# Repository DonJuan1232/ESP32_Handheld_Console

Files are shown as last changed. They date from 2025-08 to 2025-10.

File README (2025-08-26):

This project is for a self designed handheld console.
The idea is that I create a base framework so that other developers can easily create games for this "platform"

Because I wanted to learn how to design a PCB I decided to design a PCB (Also because I really didnt want to solder a lot of buttons to a prototype board :) )
Later in the projects life cycle I will add all the PCB and 3d model design files.

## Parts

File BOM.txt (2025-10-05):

Bill Of Materials for 1 "game console"

1x shell
1x lid
6x buttons
1x 2.4 inch tft ILI9341 lcd display 
1x 30 pin ESP32
5x Tactile Pushbutton Switch Momentary 4pin 6*6*6mm
1x small toggle switch | built in measurements: 8.5 x 13.5mm
1x Li-Po Battery 3.7V 1200mAh
1x Seeed Studio Lipo Rider Plus
4x 8mm long screws with a 1.8mm diameter

Hot glue to keep battery components in place

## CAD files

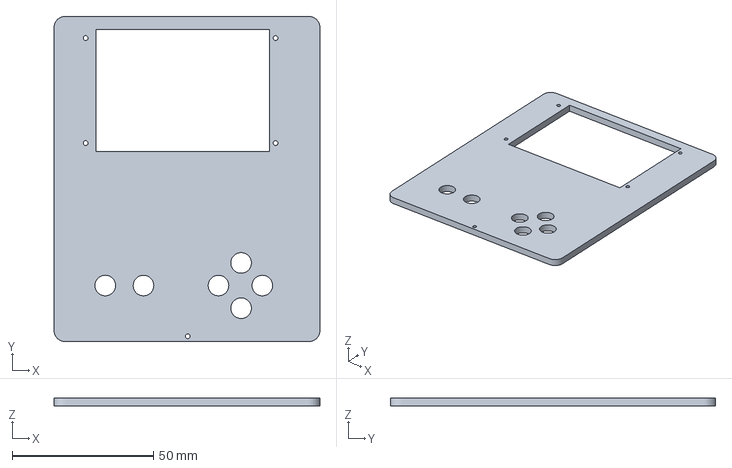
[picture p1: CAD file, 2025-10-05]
3d models/3d print files/Lid.3mf
94.0 x 115.0 x 3.00 mm

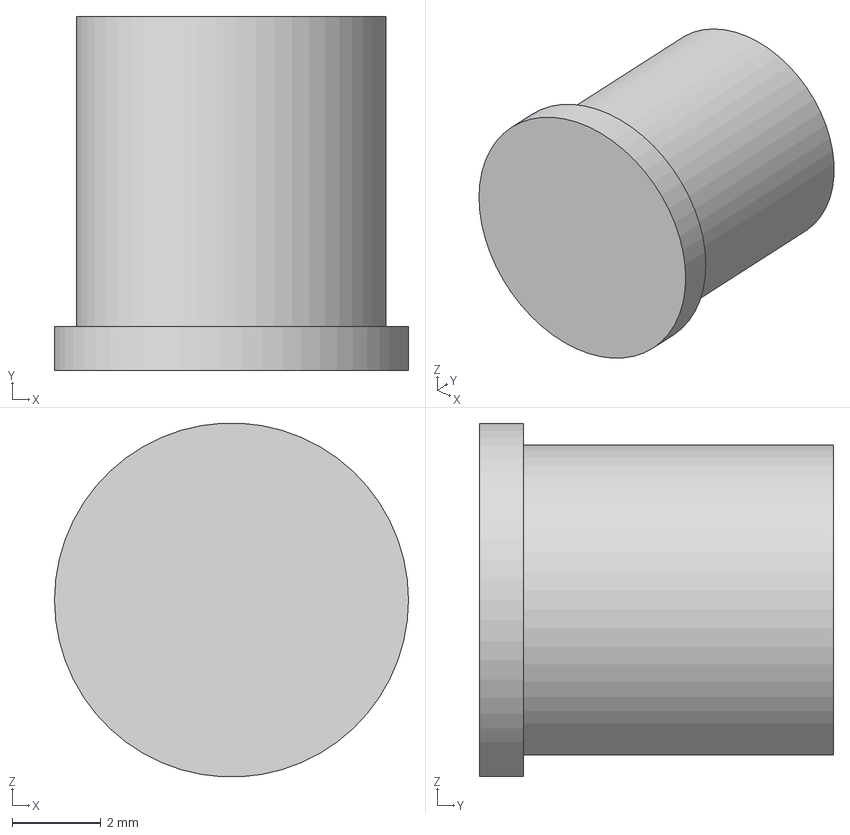
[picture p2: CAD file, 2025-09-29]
3d models/Button+cap.stp
8.00 x 8.00 x 7.99 mm

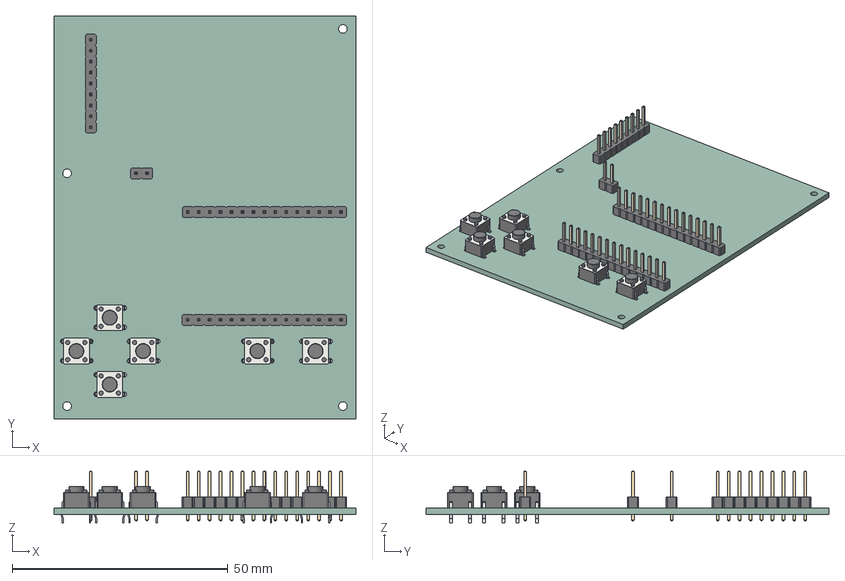
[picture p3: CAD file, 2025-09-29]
PocketGamePCB/PocketGamePCB.step
70.0 x 93.5 x 12.0 mm
PinHeader_1x15_P2.54mm_Vertical x 2
SW_PUSH_6mm_H5mm x 6
PinHeader_1x09_P2.54mm_Vertical
PinHeader_1x02_P2.54mm_Vertical
PocketGamePCB_PCB

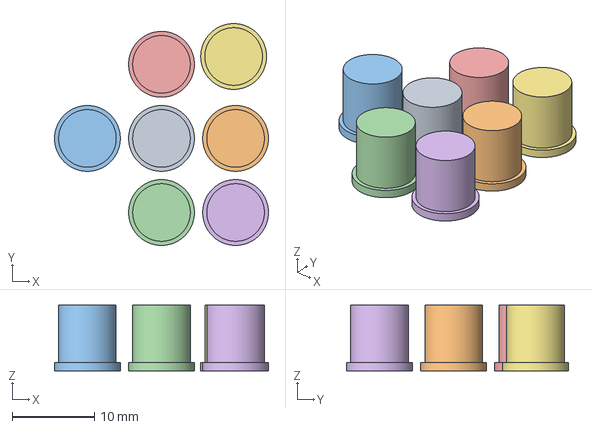
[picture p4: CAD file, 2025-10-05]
3d models/3d print files/buttons.3mf
26.0 x 26.9 x 8.00 mm

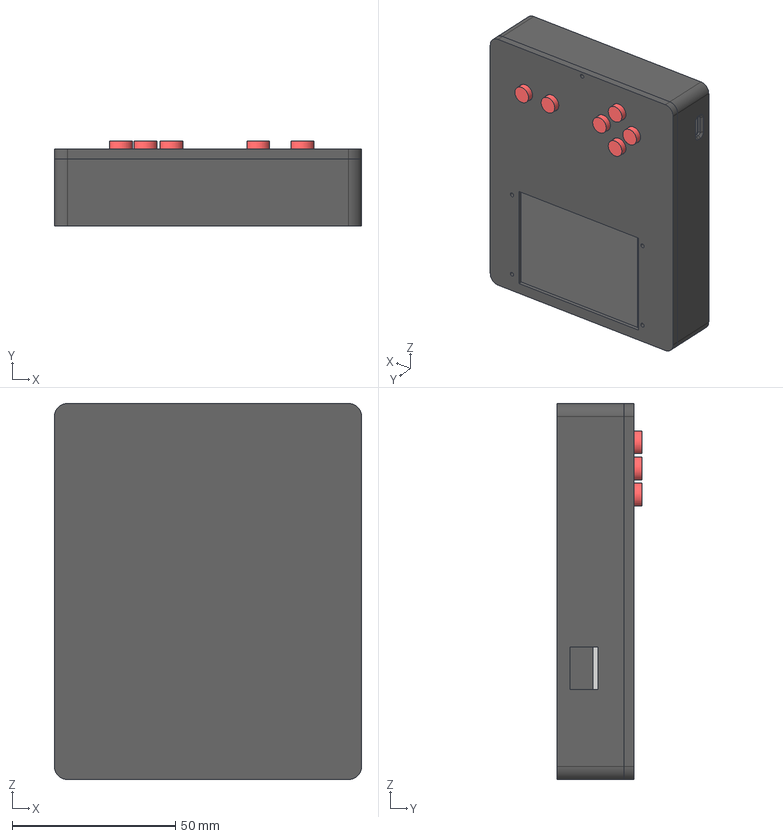
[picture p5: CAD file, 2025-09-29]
3d models/Pocket+Snake.stp
94.0 x 26.0 x 115.0 mm
2.4 inch tft lcd display
LID
Button cap x 6

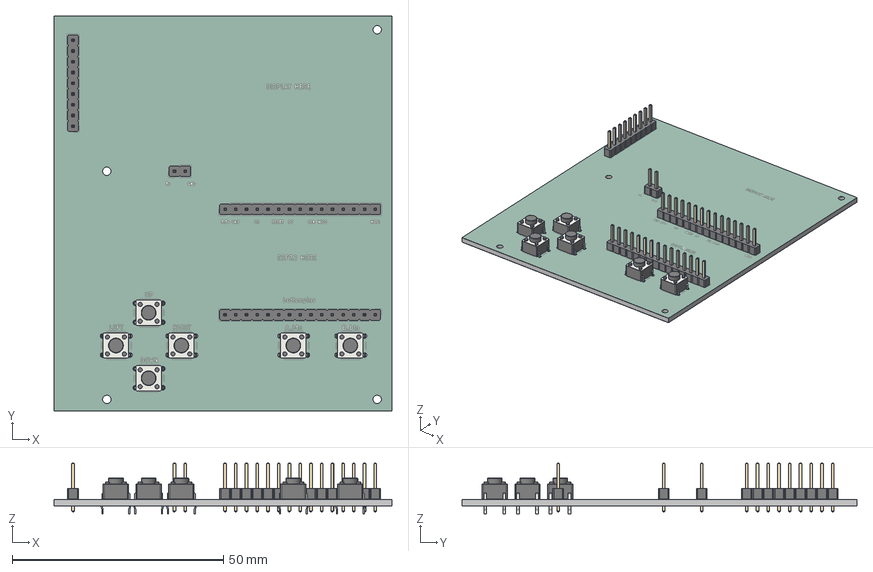
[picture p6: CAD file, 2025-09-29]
PocketGamePCB/PocketGamePCBnew.step
80.0 x 93.5 x 12.0 mm
PinHeader_1x15_P2.54mm_Vertical x 2
SW_PUSH_6mm_H5mm x 6
PinHeader_1x09_P2.54mm_Vertical
PinHeader_1x02_P2.54mm_Vertical
PocketGamePCB_silkscreen
PocketGamePCB_soldermask
PocketGamePCB_PCB

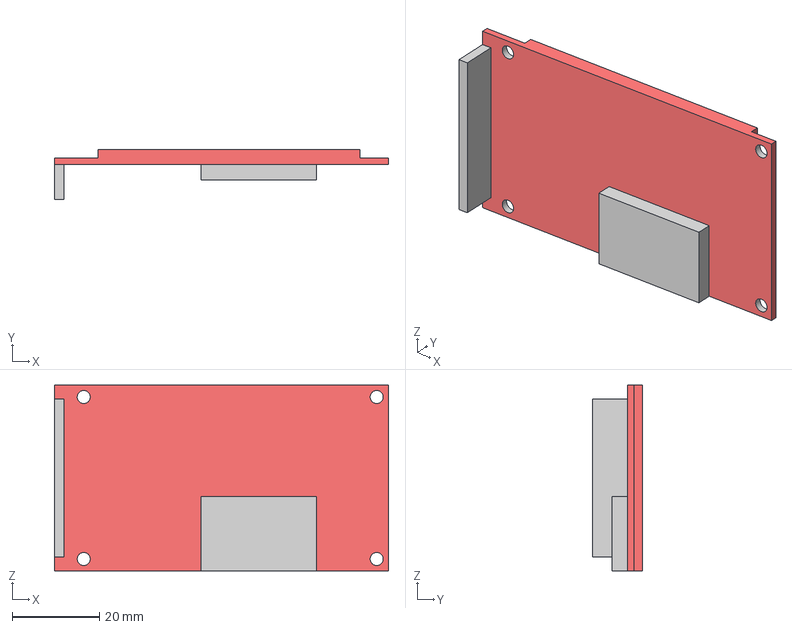
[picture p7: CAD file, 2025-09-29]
3d models/2.4 inch tft display.stp
76.5 x 11.5 x 42.5 mm

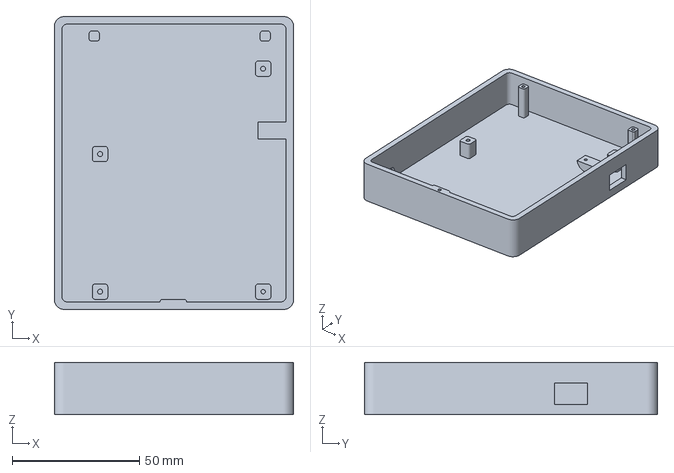
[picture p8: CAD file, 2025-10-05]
3d models/3d print files/Shell.3mf
94.0 x 115.0 x 20.5 mm

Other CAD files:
3d models/PocketGamePCBnew.stp

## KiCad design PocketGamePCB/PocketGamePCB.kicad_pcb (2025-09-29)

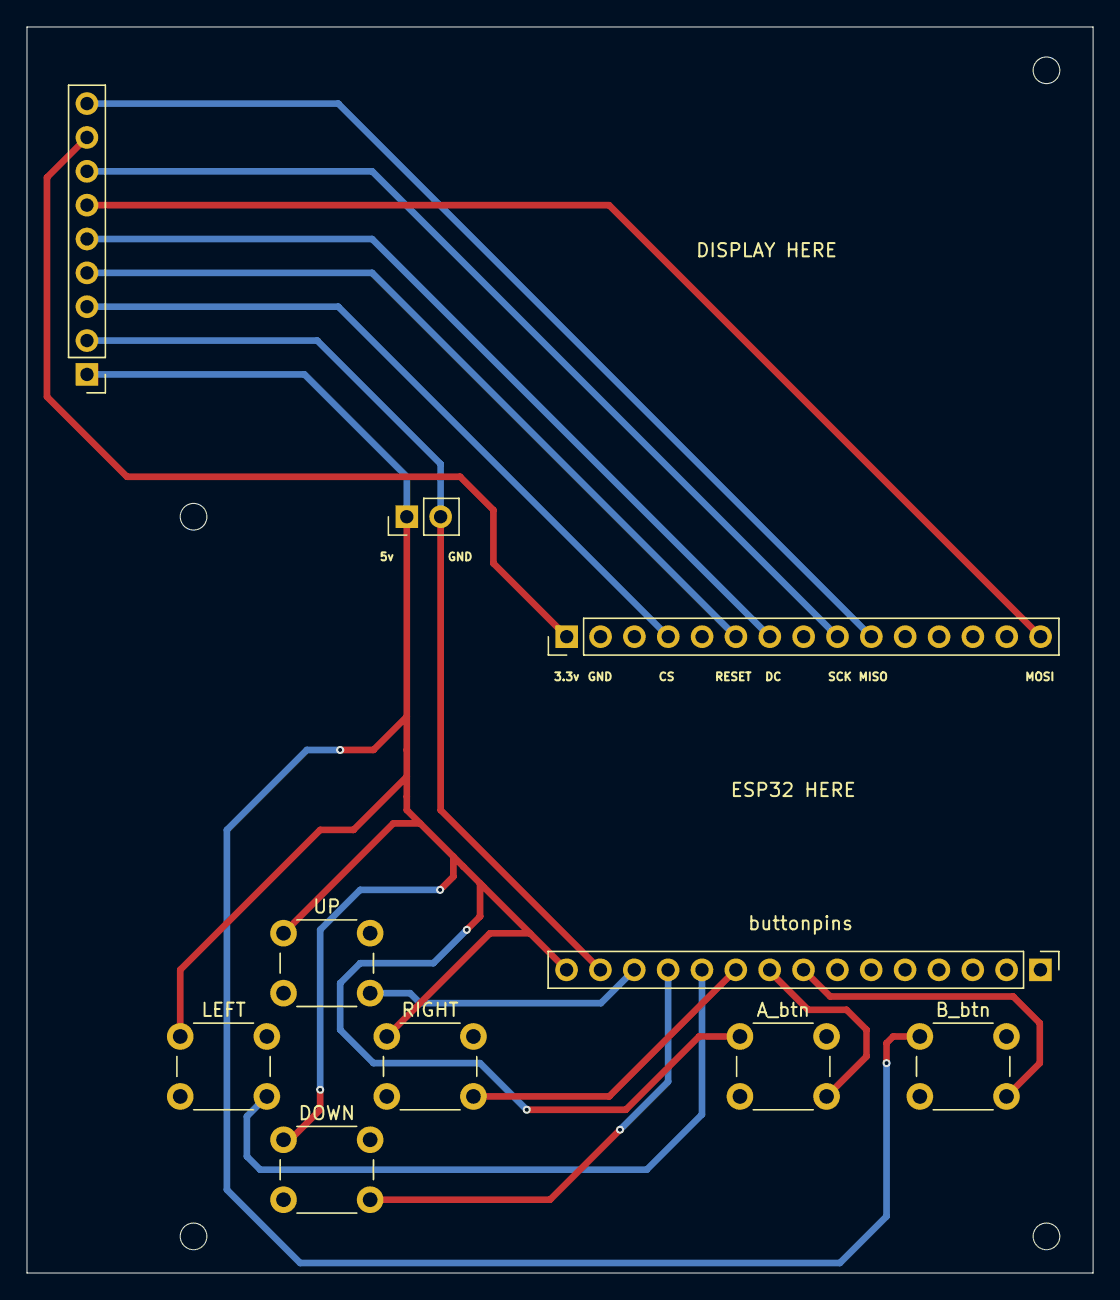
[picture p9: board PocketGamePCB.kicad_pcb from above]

Board: 2 copper layers, 80.0 x 93.5 mm, 10 parts (0 on the bottom side), 15 nets.

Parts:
5v: Conn_01x02_Pin; PinHeader_1x02_P2.54mm_Vertical
A_btn: SW_Push; SW_PUSH_6mm_H5mm
B_btn: SW_Push; SW_PUSH_6mm_H5mm
DOWN: SW_Push; SW_PUSH_6mm_H5mm
J1: Conn_01x15_Pin; PinHeader_1x15_P2.54mm_Vertical
J2: Conn_01x09_Pin; PinHeader_1x09_P2.54mm_Vertical
LEFT: SW_Push; SW_PUSH_6mm_H5mm
RIGHT: SW_Push; SW_PUSH_6mm_H5mm
UP: SW_Push; SW_PUSH_6mm_H5mm
buttonpins: Conn_01x15_Pin; PinHeader_1x15_P2.54mm_Vertical

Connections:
unnamed: J1.1, J2.8
unnamed: J1.4, J2.3
unnamed: J1.6, J2.4
unnamed: J1.7, J2.5
unnamed: J1.9, J2.7
unnamed: J1.10, J2.9
unnamed: J1.15, J2.6
unnamed: 5v.1, J2.1, buttonpins.14
unnamed: 5v.2, A_btn.1, B_btn.1, DOWN.1, J2.2, LEFT.1, RIGHT.1, UP.1, buttonpins.15
unnamed: B_btn.2, buttonpins.8
unnamed: A_btn.2, buttonpins.9
unnamed: RIGHT.2, buttonpins.10
unnamed: LEFT.2, buttonpins.11
unnamed: DOWN.2, buttonpins.12
unnamed: UP.2, buttonpins.13

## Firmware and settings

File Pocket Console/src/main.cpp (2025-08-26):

#include <Adafruit_GFX.h>
#include <Adafruit_ILI9341.h>
#include <freertos/FreeRTOS.h>
#include <freertos/task.h>
#include <stdlib.h>

#include "driver/gpio.h"
#include "esp_system.h"
#include "fruit.h"
#include "snake.h"
// Pin definitions
#define TFT_CS 2
#define TFT_DC 17
#define TFT_RST 16
#define LED_PIN 2
#define BUTTON_PIN_RIGHT 13
#define BUTTON_PIN_LEFT 12
#define BUTTON_PIN_DOWN 27
#define BUTTON_PIN_UP 14
#define BUTTON_PIN_A 25
#define BUTTON_PIN_B 26

Adafruit_ILI9341 display = Adafruit_ILI9341(TFT_CS, TFT_DC, TFT_RST);

const gpio_num_t buttonPinA = (gpio_num_t)BUTTON_PIN_A;
const gpio_num_t buttonPinB = (gpio_num_t)BUTTON_PIN_B;
const gpio_num_t buttonPinUp = (gpio_num_t)BUTTON_PIN_UP;
const gpio_num_t buttonPinDown = (gpio_num_t)BUTTON_PIN_DOWN;
const gpio_num_t buttonPinLeft = (gpio_num_t)BUTTON_PIN_LEFT;
const gpio_num_t buttonPinRight = (gpio_num_t)BUTTON_PIN_RIGHT;

uint8_t upStateA = 0;
uint8_t upStateB = 0;
uint8_t upStateUp = 0;
uint8_t upStateDown = 0;
uint8_t upStateLeft = 0;
uint8_t upStateRight = 0;

snake gameSnake;
fruit gameFruit;

void resetGame() {
    display.fillScreen(ILI9341_BLACK);
    gameSnake = snake();  // re-initialize
    gameFruit.spawnFruit(display);
}

void GameTask(void *pvParameters) {
    while (true) {
        Vector2 head = gameSnake.getLocation();

        // check boundaries
        if (head.x * 10 <= 0 || head.x * 10 >= 250 || head.y * 10 <= 0 || head.y * 10 >= 240) {
            resetGame();
        }

        // check self collision
        if (gameSnake.checkSelfCollision()) {
            resetGame();
        }

        // check fruit collision
        if ((head.x * 10) >= gameFruit.location.x - 10 && (head.x * 10) <= gameFruit.location.x + 10 &&
            (head.y * 10) >= gameFruit.location.y - 10 && (head.y * 10) <= gameFruit.location.y + 10) {
            gameFruit.deleteFruit(display);
            gameFruit.spawnFruit(display);
            gameSnake.makeLonger();
        }

        vTaskDelay(pdMS_TO_TICKS(100));
    }
}

void DisplayTask(void *pvParameters) {
    while (true) {
        display.fillScreen(ILI9341_BLACK);  // clear screen

        // Move snake every frame
        gameSnake.moveSnake();
        gameFruit.drawFruit(display);

        // Draw snake
        gameSnake.drawSnake(display);

        vTaskDelay(pdMS_TO_TICKS(100));  // snake speed (200ms per move)
    }
}
void ButtonTask(void *pvParameters) {
    const gpio_num_t ledPin = (gpio_num_t)LED_PIN;

    while (true) {
        // Read button
        upStateA = gpio_get_level(buttonPinA);
        upStateB = gpio_get_level(buttonPinB);
        upStateUp = gpio_get_level(buttonPinUp);
        upStateDown = gpio_get_level(buttonPinDown);
        upStateLeft = gpio_get_level(buttonPinLeft);
        upStateRight = gpio_get_level(buttonPinRight);

        if (upStateUp) gameSnake.changeDirection(0);
        if (upStateDown) gameSnake.changeDirection(1);
        if (upStateLeft) gameSnake.changeDirection(2);
        if (upStateRight) gameSnake.changeDirection(3);

        // Optional: delay to prevent CPU hogging
        vTaskDelay(pdMS_TO_TICKS(10));  // 10 ms
    }
}

void setup() {
    // Initialize display
    display.begin();

    uint32_t seed = esp_random();
    randomSeed(seed);
    Serial.begin(9600);

    // Configure GPIO13 as input with pull-down
    gpio_config_t io_conf = {};
    io_conf.pin_bit_mask = (1ULL << BUTTON_PIN_A) | (1ULL << BUTTON_PIN_B) | (1ULL << BUTTON_PIN_UP) | (1ULL << BUTTON_PIN_DOWN) | (1ULL << BUTTON_PIN_LEFT) | (1ULL << BUTTON_PIN_RIGHT);
    io_conf.mode = GPIO_MODE_INPUT;
    io_conf.pull_down_en = GPIO_PULLDOWN_ENABLE;
    io_conf.pull_up_en = GPIO_PULLUP_DISABLE;
    io_conf.intr_type = GPIO_INTR_DISABLE;
    gpio_config(&io_conf);

    // Configure GPIO2 as output
    gpio_set_direction((gpio_num_t)LED_PIN, GPIO_MODE_OUTPUT);

    // Draw initial graphics
    display.fillScreen(ILI9341_BLACK);

    gameFruit.spawnFruit(display);

    // Create FreeRTOS tasks
    xTaskCreate(ButtonTask, "ButtonTask", 2048, NULL, 1, NULL);
    xTaskCreate(DisplayTask, "DisplayTask", 4096, NULL, 1, NULL);
    xTaskCreate(GameTask, "GameTask", 4096, NULL, 1, NULL);
}

void loop() {
    // No need to do anything here with FreeRTOS
}

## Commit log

2025-08-26 Added project
    Added first prototype project code.
    PLAN:
    designed PCB for the project.
    Update code to more managable standard that can be easily modified for different types of games.
    add 3d models and PCB design to project files
2025-09-29 added PCB files
    [PocketGamePCB-B_Cu.gbr, PocketGamePCB-B_Mask.gbr, PocketGamePCB-B_Paste.gbr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]
2025-09-29 Added 3d models
    [2.4 inch tft display.stp, Button+cap.stp, Pocket+Snake.stp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]
2025-10-05 added files and BOM
    [Lid.3mf, Shell.3mf, buttons.3mf]
